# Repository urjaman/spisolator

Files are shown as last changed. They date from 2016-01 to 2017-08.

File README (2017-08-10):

SPI Isolator
------------

This is a PCB for allowing arbitrary motherboards
to have their SPI flash chip isolated from the
motherboard when powered off (or via control signal), 
to allow external (ISP) programming.

KiCad sources are in the repo, but
for simple purchasing, there's the PCB shared in oshpark:
https://oshpark.com/shared_projects/ZljIshjt

And the parts list:		- Example URLs
R1, R2: 4k7 0805 resistor	- http://uk.farnell.com/walsin/wr08x4701ftl/res-thick-film-4k7-1-150v-0805/dp/2502731
C1: 1u 0805 capacitor		- http://uk.farnell.com/kemet/c0805c105z3vactu/ceramic-capacitor-1uf-25v-y5v/dp/1269997
D1: schottky SOD-323 diode	- http://uk.farnell.com/nxp/pmeg2005aea/diode-schottky-sod-323/dp/8737843
U1: 74LVC4066			- http://uk.farnell.com/on-semiconductor/mc74lvxt4066dr2g/analogue-switch-quad-spst-nsoic/dp/2464564 , http://eu.mouser.com/ProductDetail/NXP-Semiconductors/74LVC4066D118
P2: 2x4 IDC header		- http://uk.farnell.com/te-connectivity-amp/826942-4/header-straight-2x4way/dp/1248160
U2: SO-8 SPI flash chip		- http://uk.farnell.com/spansion/s25fl164k0xmfi011/ic-memory-flash-64mbit-soic-8/dp/2363323

Oh, and if you like this, pizza money donations are accepted via paypal:
urjaman at gmail dot com.

Known unsupported: Quad I/O. If you have a motherboard that needs that, message me,
for a small donation I could make a version that supports Quad I/O ;)

Build Howto and Usage (beta, untested)
--------------------------------------
solder the components on the PCB, a probably fine order is
starting from the underside first...
remove the flash chip from the target machine, and attach the
PCB as near as possible to its layout (maybe with double-sided tape),
but not over the layout.
Connect small (patch, "green wire") wires from the 6 places
on the edge of the PCB to the layout

the 2x4 ISP connector is compatible with the one in the PC Engines
APU series, so if you have an ISP lead for them, it should work
for this, otherwise, the pinout is:
3V3 1 2 GND
!CS 3 4 SCK
 SO 5 6 SI
--  7 8 buffer en/!dis

NOTE: The 160129 version was not compatible with the APU pinout
(which is a dediprog programming pinout), the MOSI and MISO were accidentally
swapped.

The analog switch/buffer is normally controlled by 
the 3V3 power on the motherboard, so the chip is externally
programmable when the motherboard 3.3V supply is OFF

The buffer control line is an extension to the APU
connector (it had nothing there), that can be used 
to program externally even if the target motherboard
is running. To do that, connect pin 8 of the ISP header to ground,
but preferably not too hard;
if you connect the header the wrong way around and there is some other
ground connection between the programmer and the motherboard (eg. RS232),
this would connect the 3V3 line to ground.
So a suggested safer circuit is:

pin 8 - 50 ohm - switch - pin 2 

With parts for this extension:
http://uk.farnell.com/multicomp/mcknp03uj0500b00/resistor-wirewound-50r-5-3w/dp/1903828
http://uk.farnell.com/multicomp/mcr13-5-05/switch-toggle-spst-off-on-so/dp/2128120

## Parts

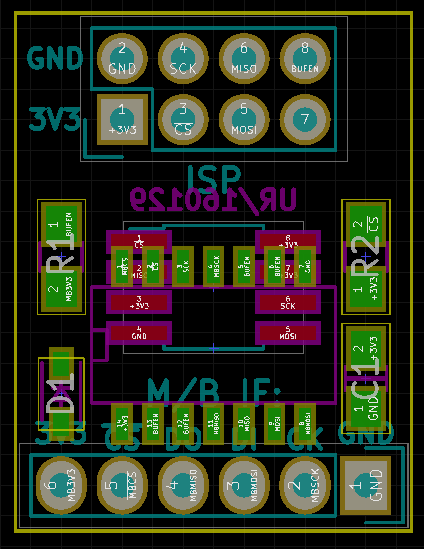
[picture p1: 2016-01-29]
component-placement.png

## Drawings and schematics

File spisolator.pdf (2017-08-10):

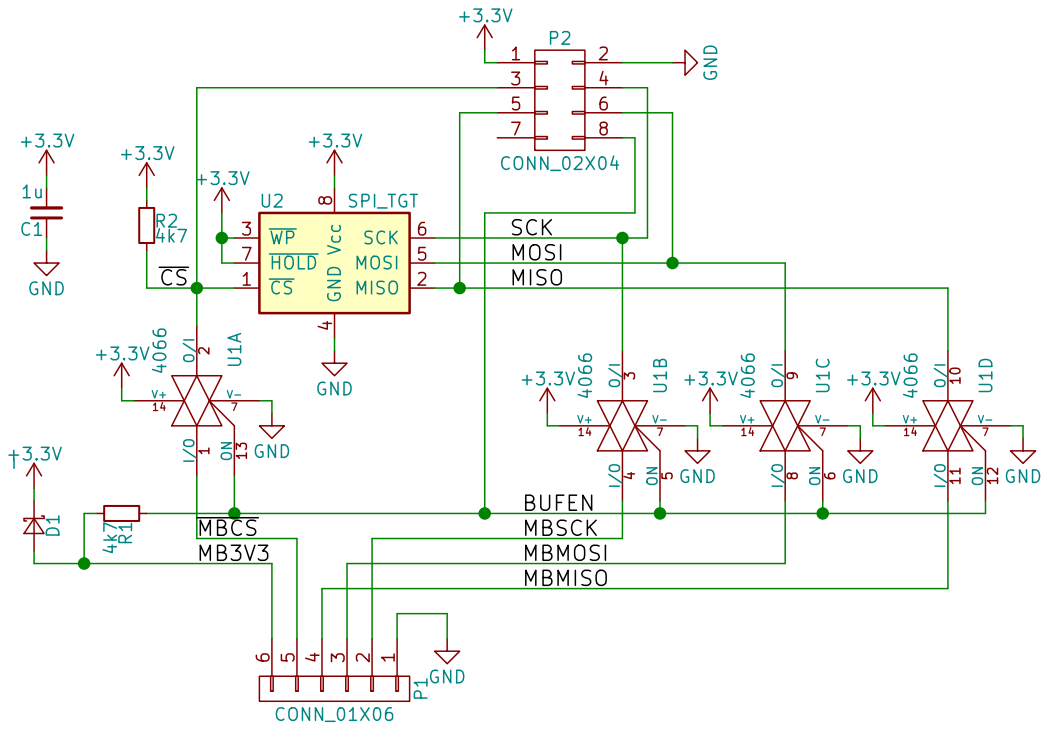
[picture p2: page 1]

4 MOSI 5 SCK 6 HOLD 7 Vcc U2 8SPI_TGT

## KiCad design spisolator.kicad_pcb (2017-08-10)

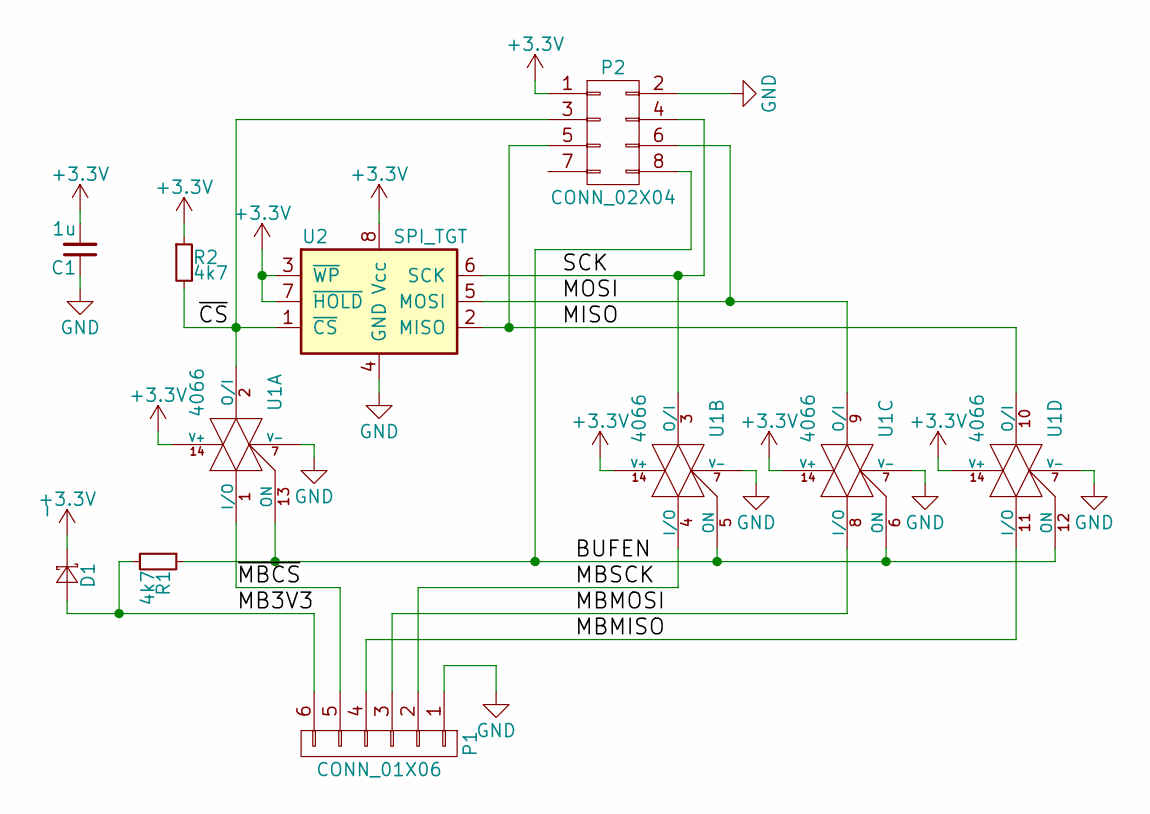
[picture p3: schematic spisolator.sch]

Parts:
C1: 1u; C_0805_HandSoldering
D1: -; SOD-323
P1: CONN_01X06; Socket_Strip_Straight_1x06
P2: CONN_02X04; Pin_Header_Straight_2x04
R1, R2: 4k7; R_0805_HandSoldering
U1: 4066; SOIC-14_N
U2: SPI_TGT; SOIC-8_3.9x4.9mm_Pitch1.27mm

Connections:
+3V3: C1.2, D1.1 (K), P2.1, R2.1, U1.14 (V+), U2.3 (~WP), U2.7 (~HOLD), U2.8 (Vcc)
/BUFEN: P2.8, R1.1, U1.5 (ON), U1.6 (ON), U1.12 (ON), U1.13 (ON)
/MB3V3: D1.2 (A), P1.6, R1.2
/MBMISO: P1.4, U1.11 (I/O)
/MBMOSI: P1.3, U1.8 (I/O)
/MBSCK: P1.2, U1.4 (I/O)
/MISO: P2.5, U1.10 (O/I), U2.2 (MISO)
/MOSI: P2.6, U1.9 (O/I), U2.5 (MOSI)
/SCK: P2.4, U1.3 (O/I), U2.6 (SCK)
/~CS: P2.3, R2.2, U1.2 (O/I), U2.1 (~CS)
/~MBCS: P1.5, U1.1 (I/O)
GND: C1.1, P1.1, P2.2, U1.7 (V-), U2.4 (GND)

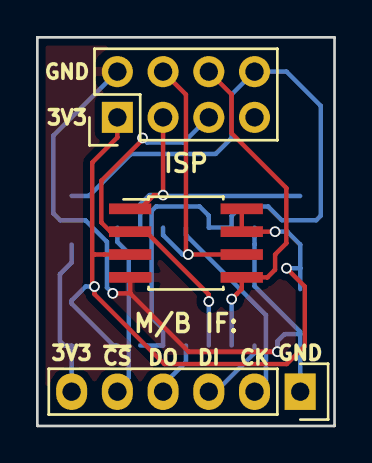
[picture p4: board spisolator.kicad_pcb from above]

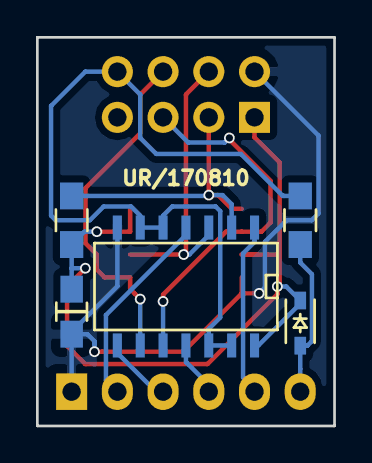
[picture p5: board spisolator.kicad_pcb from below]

Board: 2 copper layers, 16.5 x 21.6 mm, 8 parts (5 on the bottom side), 12 nets.

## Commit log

2016-01-28 add the diode to the parts list
2016-01-29 new part positions for the new pcb
2016-02-03 kicad sources for the SPI Isolator, and the gerber files
    [spisolator-B.Cu.gbr, spisolator-B.Mask.gbr, spisolator-B.SilkS.gbr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]
2016-02-03 to be released stuff, r2 of the PCB
    [spisolator-B.Cu.gbr, spisolator-B.Mask.gbr, spisolator-B.SilkS.gbr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]
2016-02-03 Change the state of the project to really open sourced
    And included my paypal, just in case somebody wants to give me money still
2017-08-10 Fix swapped MISO/MOSI in the programming connector
    [spisolator-B.Cu.gbr, spisolator-B.Mask.gbr, spisolator-B.SilkS.gbr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]
